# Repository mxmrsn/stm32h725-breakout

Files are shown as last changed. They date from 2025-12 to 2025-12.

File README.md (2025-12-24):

# STM32H725-Breakout

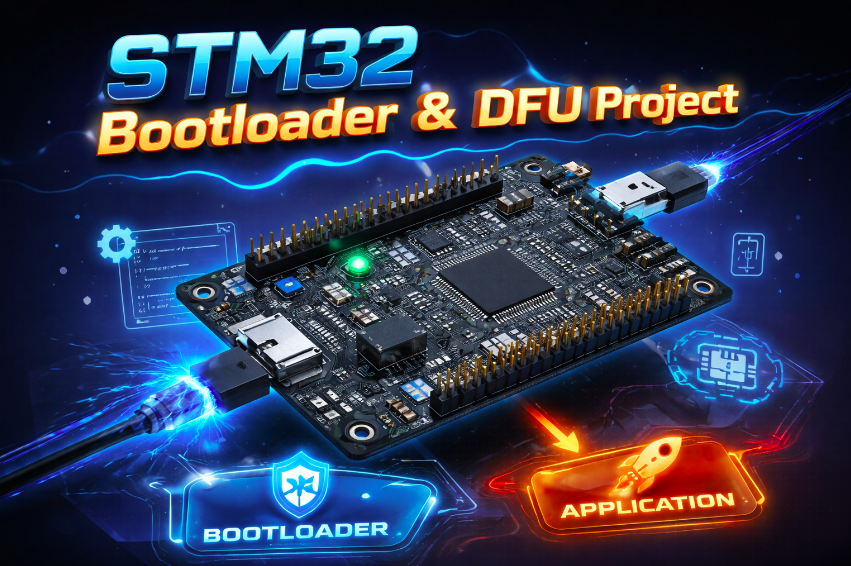
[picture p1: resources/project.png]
STM Bootloader & DFU

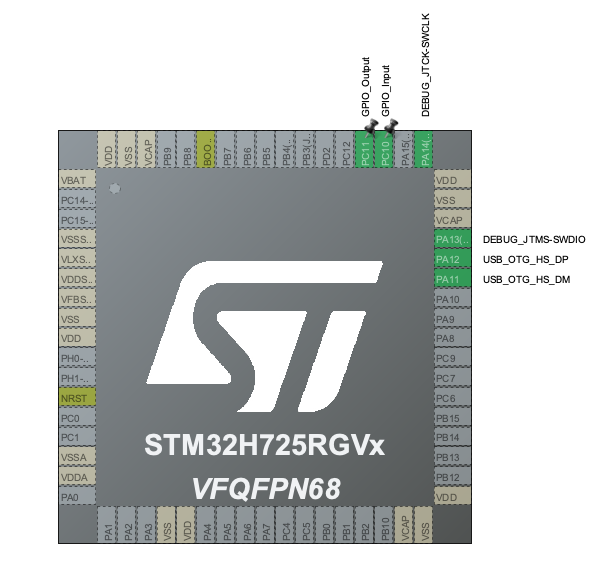
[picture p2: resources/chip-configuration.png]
chip configuration


## Flash Layout
The memory of the chip is configured where the first 128kB are dedicated to the bootloader, then the rest is for the main application. Seee in ```../bootloader/Core/Src/main.c```:

```
#define APP_ADDRESS 0x08020000
```

## Clock Configuration
The clock is optimized to run 48MHz on the USB comms, and ~530Hz main clock rate.

## DFU Trigger
To put the chip into bootloader mode, we configure this by holding GPIO PC10 button down. Then the LED connected to GPIO PC11 should heartbeat at 1Hz.

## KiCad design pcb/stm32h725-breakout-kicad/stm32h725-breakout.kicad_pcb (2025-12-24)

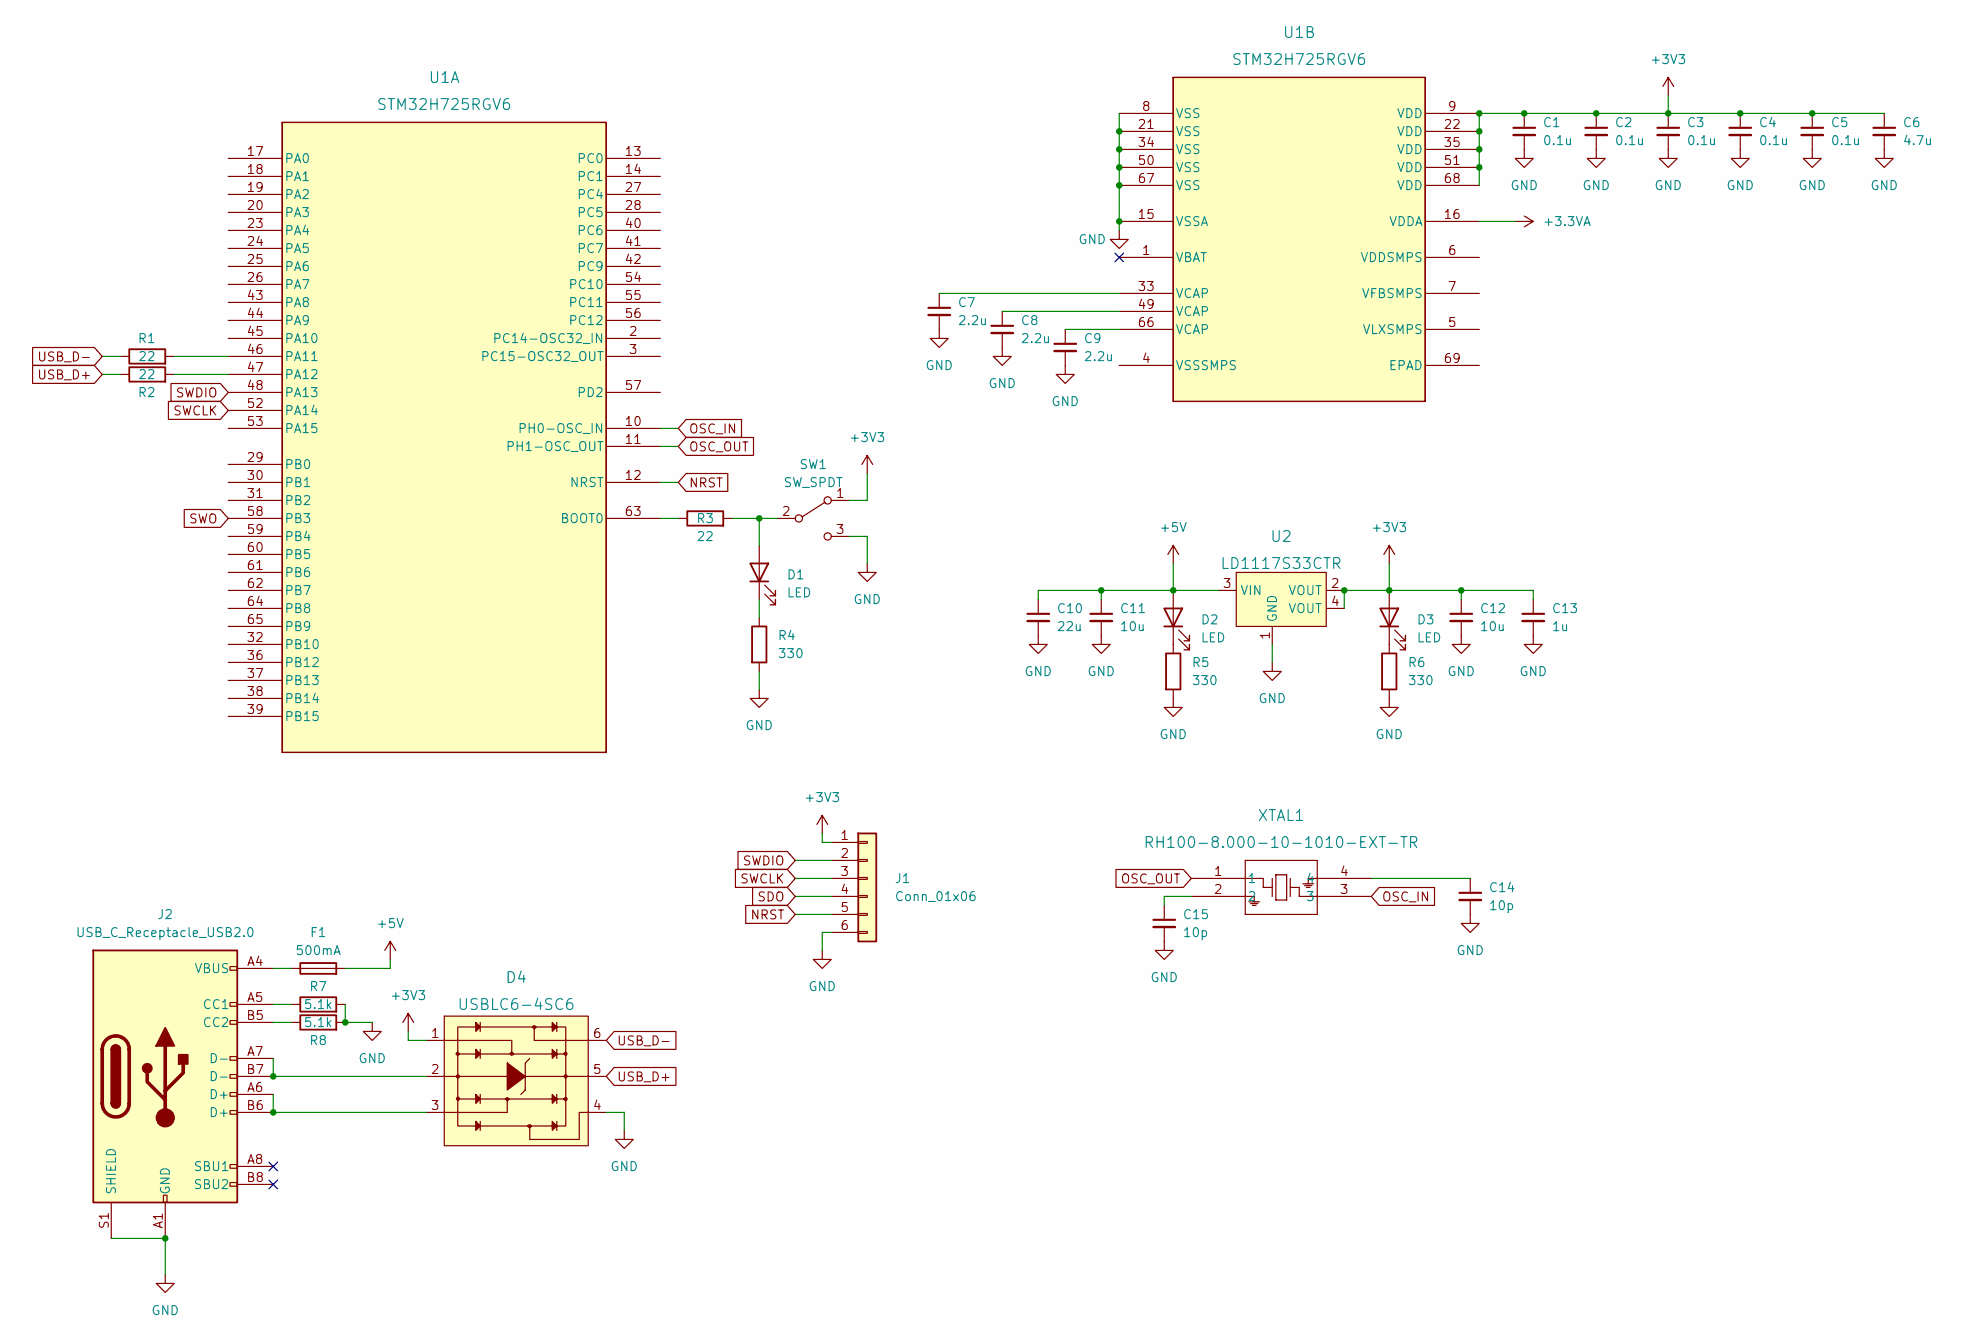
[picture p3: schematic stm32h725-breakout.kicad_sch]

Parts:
C1, C2, C3, C4, C5: 0.1u; C_0603_1608Metric
C6: 4.7u; C_0603_1608Metric
C7, C8, C9: 2.2u; C_0603_1608Metric
C10: 22u; C_0603_1608Metric
C11, C12: 10u; C_0603_1608Metric
C13: 1u; C_0603_1608Metric
C14, C15: 10p; C_0603_1608Metric
D1: LED
D2, D3: LED; LED_0805_2012Metric
D4: USBLC6-4SC6; SOT23-6L; MPN USBLC6-4SC6; Digi-Key_PN 497-4492-1-ND
F1: 500mA; Fuse_0805_2012Metric
J1: Conn_01x06; Hirose_FH12-8S-0.5SH_1x08-1MP_P0.50mm_Horizontal
J2: USB_C_Receptacle_USB2.0
R1, R2, R3: 22; R_0603_1608Metric
R4, R5, R6: 330; R_0603_1608Metric
R7, R8: 5.1k; R_0603_1608Metric
SW1: SW_SPDT; SW_SPST_B3U-1000P
U1: STM32H725RGV6; VFQFPN68_8x8mm_STM
U2: LD1117S33CTR; SOT-223; MPN LD1117S33CTR; Digi-Key_PN 497-1241-1-ND
XTAL1: RH100-8.000-10-1010-EXT-TR; RH100_RAL

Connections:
+3.3VA: U1.16 (VDDA)
+3V3: C1.1, C2.1, C3.1, C4.1, C5.1, C6.1, C12.1, C13.1, D3.2 (A), D4.1, J1.1, SW1.1 (A), U1.9 (VDD), U1.22 (VDD), U1.35 (VDD), U1.51 (VDD), U1.68 (VDD), U2.2 (VOUT), U2.4 (VOUT)
+5V: C10.1, C11.1, D2.2 (A), F1.2, U2.3 (VIN)
GND: C1.2, C2.2, C3.2, C4.2, C5.2, C6.2, C7.2, C8.2, C9.2, C10.2, C11.2, C12.2, C13.2, C14.2, C15.2, D4.4, J1.6, J2.A1 (GND), J2.A12 (GND), J2.B1 (GND), J2.B12 (GND), J2.S1 (SHIELD), R4.2, R5.2, R6.2, R7.2, R8.2, SW1.3 (C), U1.8 (VSS), U1.15 (VSSA), U1.21 (VSS), U1.34 (VSS), U1.50 (VSS), U1.67 (VSS), U2.1 (GND)
NRST: J1.5, U1.12 (NRST)
unnamed: C7.1, U1.33 (VCAP)
unnamed: C8.1, U1.49 (VCAP)
unnamed: C9.1, U1.66 (VCAP)
unnamed: C14.1, XTAL1.4
unnamed: C15.1, XTAL1.2
unnamed: D1.1 (K), R4.1
unnamed: D1.2 (A), R3.2, SW1.2 (B)
unnamed: D2.1 (K), R5.1
unnamed: D3.1 (K), R6.1
unnamed: F1.1, J2.A4 (VBUS), J2.A9 (VBUS), J2.B4 (VBUS), J2.B9 (VBUS)
unnamed: J2.A5 (CC1), R7.1
unnamed: D4.3, J2.A6 (D+), J2.B6 (D+)
unnamed: D4.2, J2.A7 (D-), J2.B7 (D-)
unnamed: J2.B5 (CC2), R8.1
unnamed: R3.1, U1.63 (BOOT0)
unnamed: R1.2, U1.46 (PA11)
unnamed: R2.2, U1.47 (PA12)
OSC_IN: U1.10 (PH0-OSC_IN), XTAL1.3
OSC_OUT: U1.11 (PH1-OSC_OUT), XTAL1.1
SDO: J1.4
SWCLK: J1.3, U1.52 (PA14)
SWDIO: J1.2, U1.48 (PA13)
SWO: U1.58 (PB3)
USB_D+: D4.5, R2.1
USB_D-: D4.6, R1.1

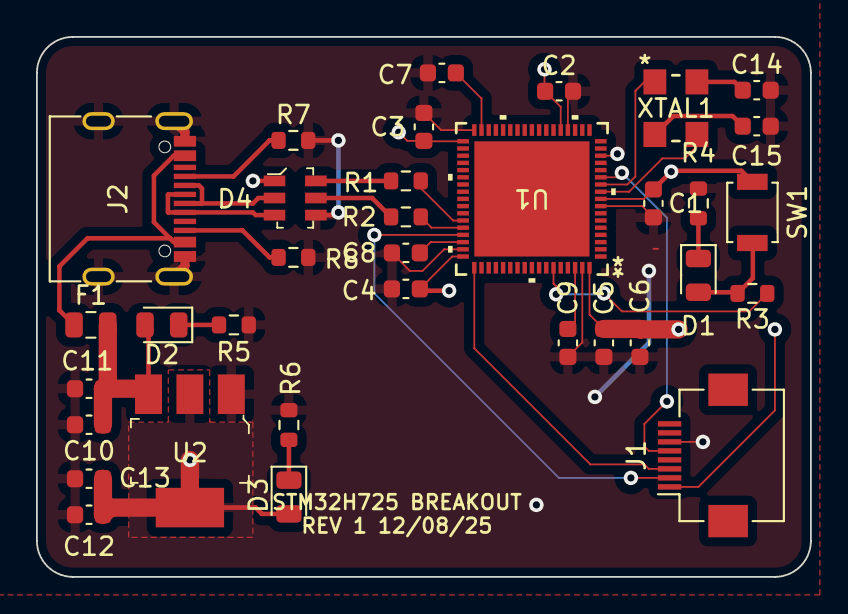
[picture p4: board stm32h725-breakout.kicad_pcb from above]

Board: 2 copper layers, 43.0 x 30.0 mm, 34 parts (0 on the bottom side), 27 nets.

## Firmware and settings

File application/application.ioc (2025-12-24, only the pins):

Mcu.UserName=STM32H725RGVx
PA11.Signal=USB_OTG_HS_DM
PA12.Signal=USB_OTG_HS_DP
PA13(JTMS/SWDIO).Signal=DEBUG_JTMS-SWDIO
PA14(JTCK/SWCLK).Signal=DEBUG_JTCK-SWCLK
PC10.Signal=GPIO_Input
PC11.Signal=GPIO_Output

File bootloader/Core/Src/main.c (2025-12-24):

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
/* Includes ------------------------------------------------------------------*/
#include "main.h"
#include "usb_device.h"
#include "gpio.h"

/* USER CODE BEGIN PD */
#define APP_ADDRESS 0x08020000 // assumes 128kb bootloader
typedef void (*pAppFunc)(void);
/* USER CODE END PD */


void SystemClock_Config(void);
void JumpToApplication(void);
uint8_t DFU_Requested(void);
/**
  * @brief  The application entry point.
  * @retval int
  */
int main(void)
{
  /* MCU Configuration--------------------------------------------------------*/

  /* Reset of all peripherals, Initializes the Flash interface and the Systick. */
  HAL_Init();

  /* Configure the system clock */
  SystemClock_Config();

  /* Initialize all configured peripherals */
  MX_GPIO_Init();

  /* USER CODE BEGIN 2 */
  /* Configure LED pin as output (if not already in MX_GPIO_Init) */
  GPIO_InitTypeDef GPIO_InitStruct = {0};
  GPIO_InitStruct.Pin = GPIO_PIN_11;
  GPIO_InitStruct.Mode = GPIO_MODE_OUTPUT_PP;
  GPIO_InitStruct.Pull = GPIO_NOPULL;
  GPIO_InitStruct.Speed = GPIO_SPEED_FREQ_LOW;
  HAL_GPIO_Init(GPIOC, &GPIO_InitStruct);

  // Check for DFU trigger
  if (DFU_Requested()) {
      // Initialize USB DFU device
      MX_USB_DEVICE_Init();
      
      while (1) {
          // DFU process handled in USB interrupt
          HAL_GPIO_TogglePin(GPIOC, GPIO_PIN_11); // heartbeat when in dfu mode
          HAL_Delay(500);
      }
  } else {
      // Jump to application
      JumpToApplication();
  }
  /* USER CODE END 2 */

  /* Infinite loop */
  /* USER CODE BEGIN WHILE */
  while (1)
  {
    /* USER CODE END WHILE */
    // should never reach here
    /* USER CODE BEGIN 3 */
  }
  /* USER CODE END 3 */
}

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
/* USER CODE BEGIN 4 */
void JumpToApplication(void)
{
    uint32_t appStack = *(__IO uint32_t*)APP_ADDRESS;
    uint32_t appEntry = *(__IO uint32_t*)(APP_ADDRESS + 4);

    // Deinitialize peripherals
    HAL_RCC_DeInit();
    HAL_DeInit();

    // Set Main Stack Pointer
    __set_MSP(appStack);

    // Jump to application reset handler
    pAppFunc app = (pAppFunc)appEntry;
    app();
}
uint8_t DFU_Requested(void)
{
    if(HAL_GPIO_ReadPin(GPIOC, GPIO_PIN_10) == GPIO_PIN_RESET) // dfu button trigger PC10
    {
        HAL_Delay(20); // 20ms debounce
        if(HAL_GPIO_ReadPin(GPIOC, GPIO_PIN_10) == GPIO_PIN_RESET)
            return 1;
    }
    return 0;
}
/* USER CODE END 4 */
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

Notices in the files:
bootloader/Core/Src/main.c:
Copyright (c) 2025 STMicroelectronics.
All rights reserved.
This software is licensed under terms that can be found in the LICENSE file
